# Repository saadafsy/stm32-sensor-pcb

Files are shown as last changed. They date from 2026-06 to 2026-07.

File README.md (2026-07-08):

# STM32F411 Sensor Telemetry Board — Firmware

Bare-metal C (no HAL, direct CMSIS) + FreeRTOS firmware for a custom **4-layer** STM32F411RET6
sensor telemetry board. A BME280 environmental sensor and a 128×64 **SSD1306 OLED** share one
400 kHz I²C bus, arbitrated by a FreeRTOS mutex. Sensor readings are framed with a CRC-16/CCITT
protocol and streamed at 921600 baud over a CP2102N USB-UART bridge to a Python visualizer.

<p align="center">
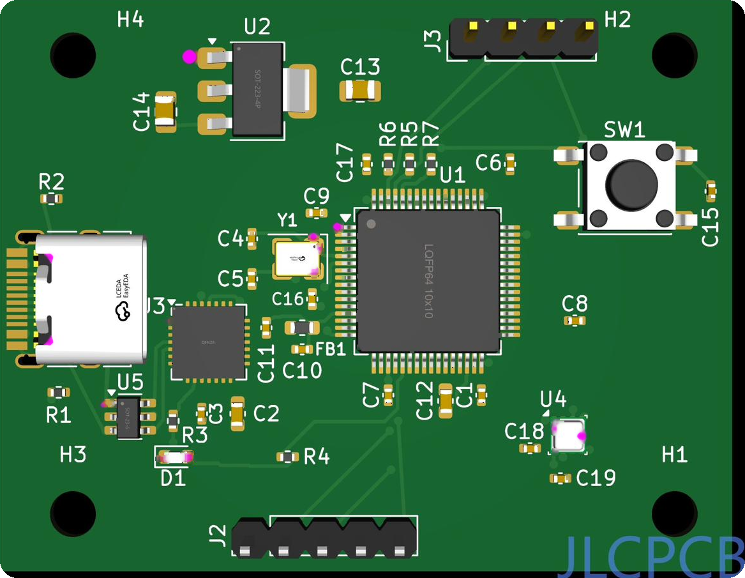
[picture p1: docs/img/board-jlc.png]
  
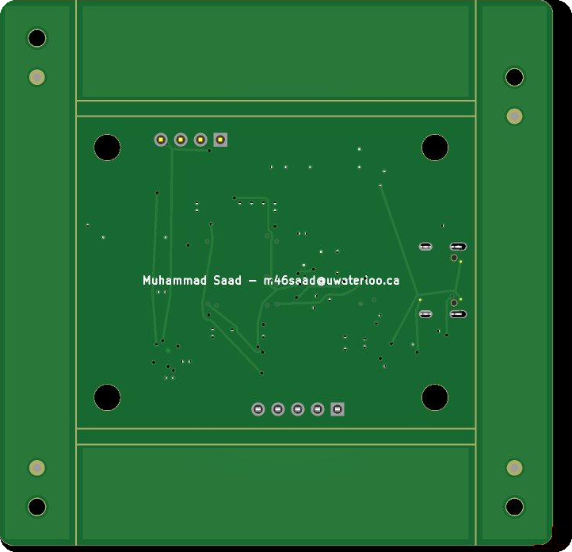
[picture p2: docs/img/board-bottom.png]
  
</p>

## Architecture — four FreeRTOS tasks
- **sensor_task** — reads + Bosch-compensates the BME280 over I²C, pushes samples to a queue
- **telemetry_task** — builds the CRC-framed binary packet and sends it under a UART mutex
- **display_task** — renders pages to the SSD1306; a **PA0/EXTI0 button** cycles pages via an ISR notification
- **heartbeat_task** — blinks the PA5 LED and kicks the IWDG watchdog

Shared I²C access is protected by an `i2c_mutex`; an `i2c_bus_recovery()` routine frees a wedged bus.

## Hardware (locked spec)
- MCU: **STM32F411RET6, LQFP-64** (LCSC C94355)
- PCB: **4-layer** — `F.Cu` signal / `In1.Cu` ground plane / `In2.Cu` +3V3 plane / `B.Cu` signal, 1.6 mm FR4
- BME280 @ I²C **0x77** (SDO→+3V3) · SSD1306 @ I²C **0x3C** · CP2102N USB-UART
- Clock: 8 MHz HSE → PLL → 100 MHz

## Layout
```
Core/Inc/   headers (clock, gpio, uart, i2c, bme280, crc, protocol, ssd1306, iwdg, FreeRTOSConfig)
Core/Src/   sources (+ main.c with the four tasks and the EXTI button ISR)
tools/      visualize.py — host-side telemetry viewer
hardware/   KiCad project (schematic, PCB, project)
docs/img/   board renders
```

## Build
Import into **STM32CubeIDE** as a bare-metal + FreeRTOS project for the STM32F411RET6
(develop on a NUCLEO-F411RE, deploy on the custom PCB). Flash over SWD/ST-Link.

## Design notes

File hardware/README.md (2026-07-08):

# Hardware

Custom 4-layer PCB designed in KiCad 9 (stackup: F.Cu / inner GND / inner +3V3 / B.Cu).

- `sensor-telemetry-board.kicad_pro` - project
- `sensor-telemetry-board.kicad_sch` - schematic
- `sensor-telemetry-board.kicad_pcb` - 4-layer layout

## Key parts

| Ref | Part | Role |
|-----|---|---|
| U1 | STM32F411CEU6 | MCU (Cortex-M4F, 100 MHz) |
| U? | BME280 | temperature / humidity / pressure over I2C |
| U? | CP2102N | USB-C to UART bridge |
| U? | AMS1117-3.3 | 3.3 V LDO |
| U? | USBLC6-2 | USB data-line ESD protection |
| Y1 | 8 MHz crystal | HSE reference for the 100 MHz PLL |

## Status

Design complete and DFM-validated (POFV across all vias); Gerbers, BOM, and CPL
can be regenerated from this project for a JLCPCB PCBA order. The board is in shipping 
and will be brought up soon (see the top-level README for status).

To export fabrication files: open the project in KiCad and run the Fabrication
Toolkit plugin, or export Gerbers / drill / BOM / CPL manually from the PCB and
schematic editors.

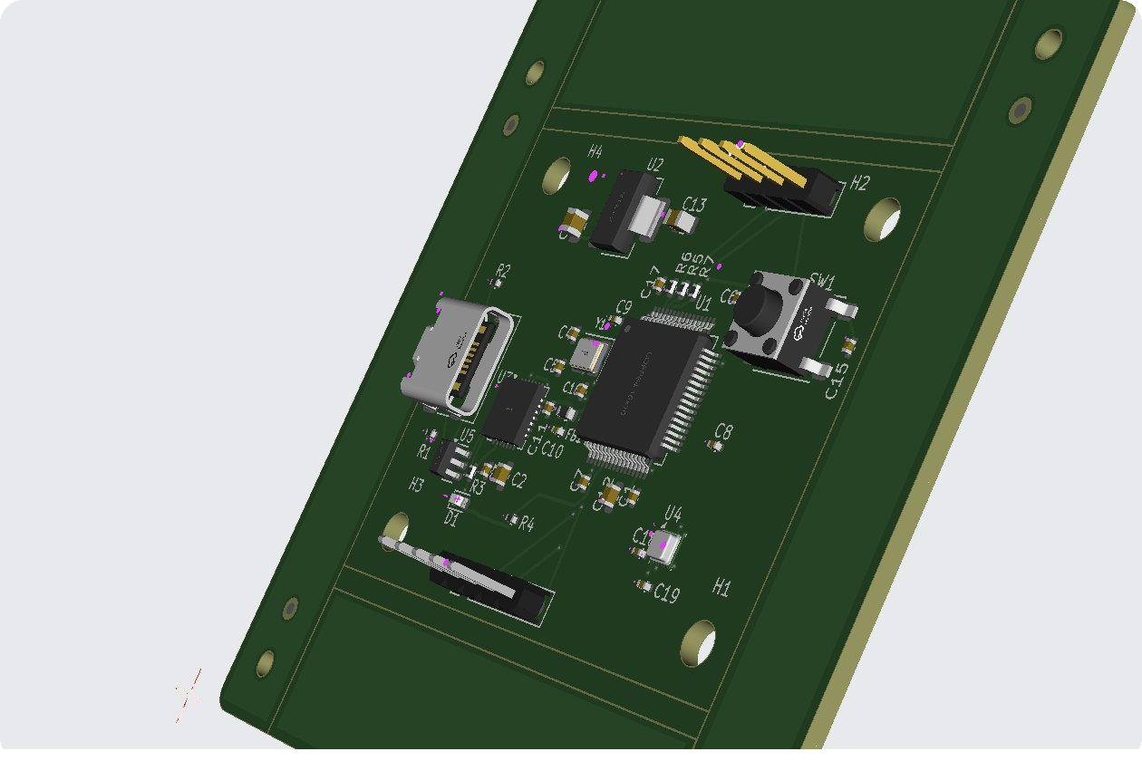
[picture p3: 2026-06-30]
docs/img/board-angled.png

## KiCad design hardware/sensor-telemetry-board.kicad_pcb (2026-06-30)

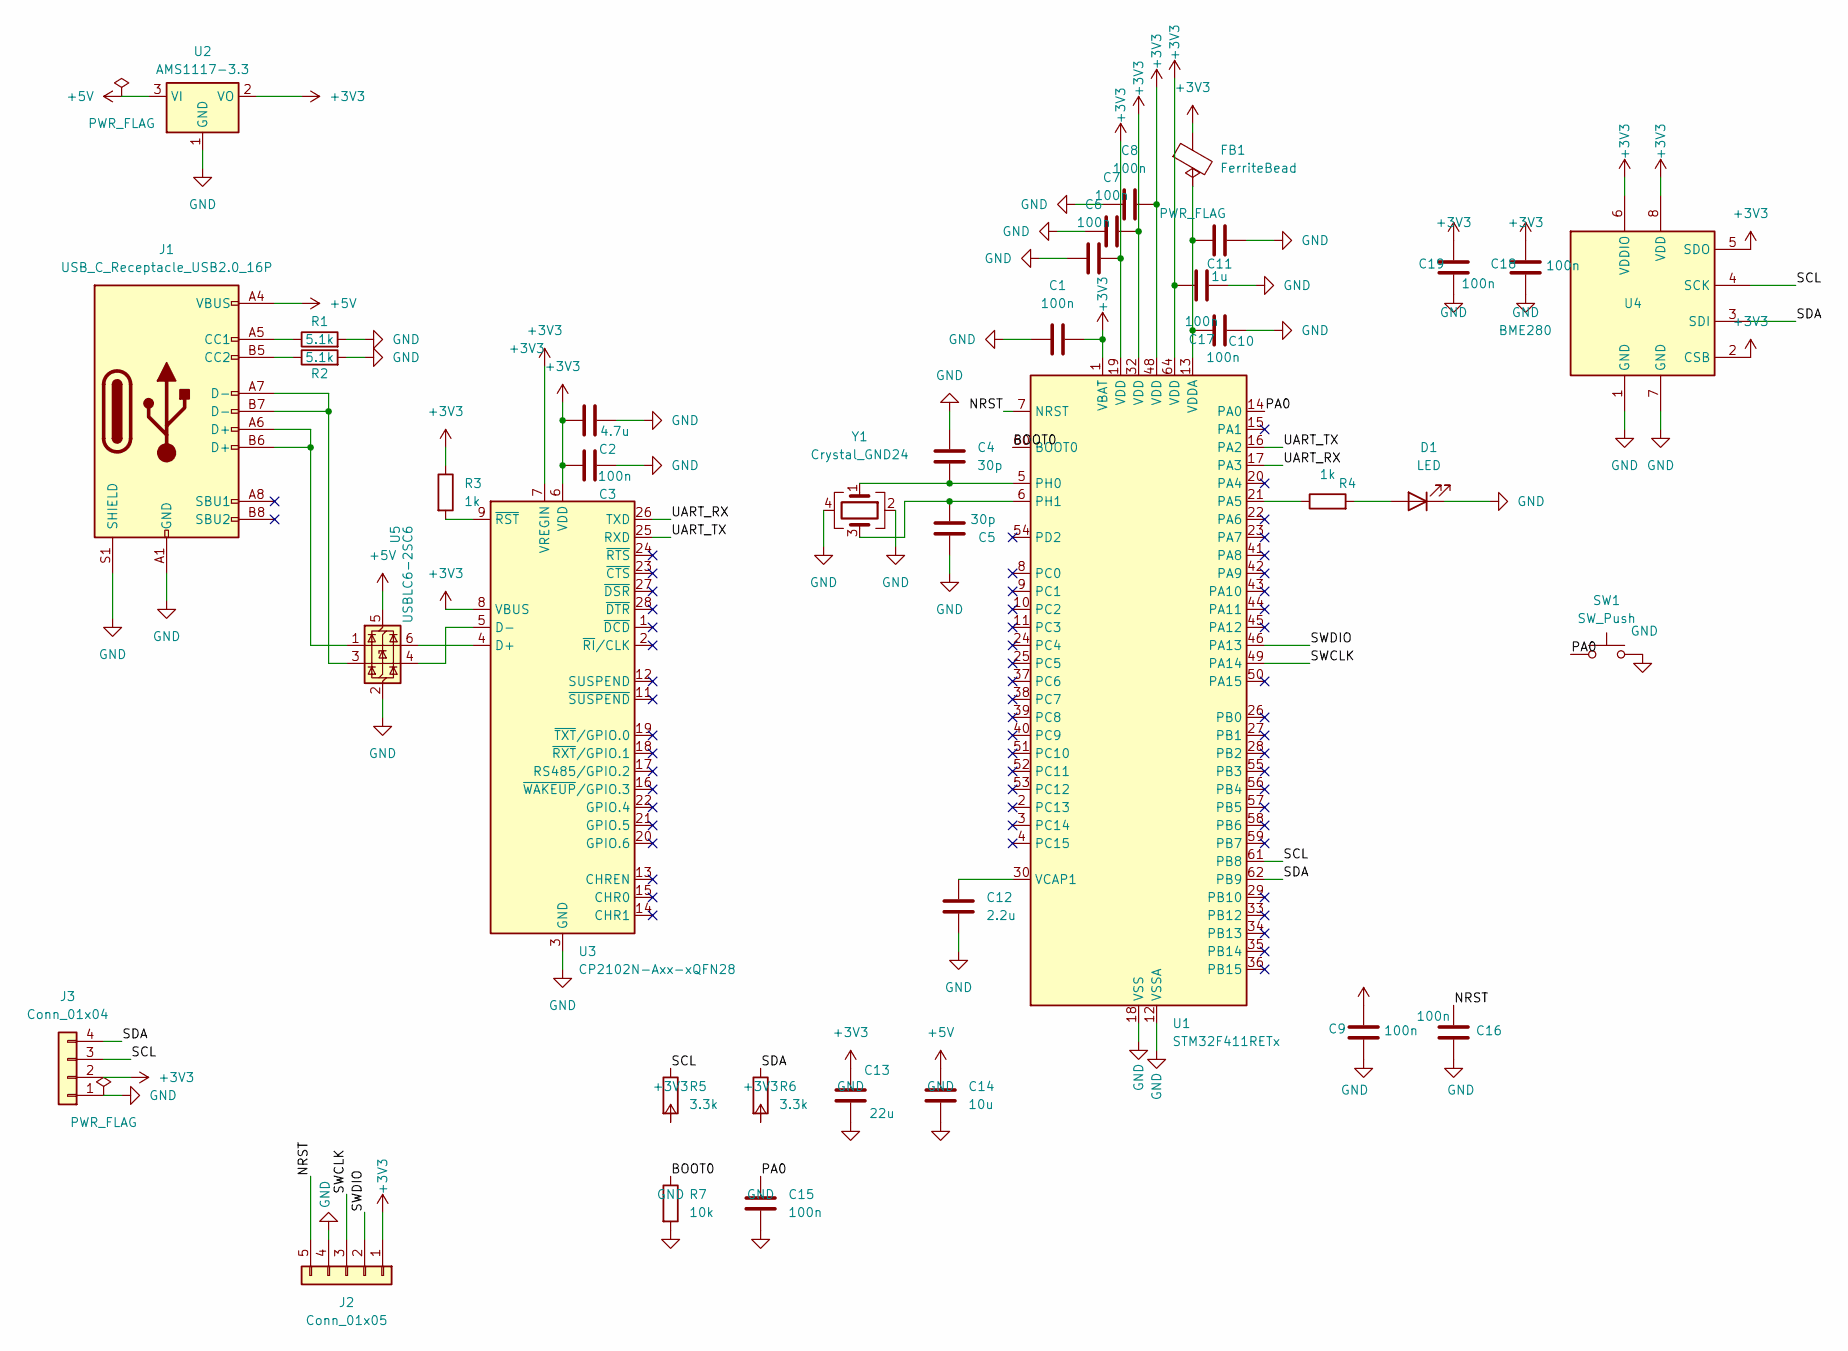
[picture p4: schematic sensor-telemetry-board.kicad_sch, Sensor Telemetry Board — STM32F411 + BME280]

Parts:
C1, C3, C6, C7, C8, C9, C10, C15, C16, C17, C18, C19: 100n; C_0402_1005Metric
C2: 4.7u; C_0603_1608Metric
C4, C5: 30p; C_0402_1005Metric
C11: 1u; C_0402_1005Metric
C12: 2.2u; C_0603_1608Metric
C13: 22u; C_0805_2012Metric
C14: 10u; C_0805_2012Metric
D1: LED; LED_0603_1608Metric
FB1: FerriteBead; L_0603_1608Metric
J1: USB_C_Receptacle_USB2.0_16P; USB_C_Receptacle_HRO_TYPE-C-31-M-12
J2: Conn_01x05; PinHeader_1x05_P2.54mm_Vertical
J3: Conn_01x04; PinHeader_1x04_P2.54mm_Vertical
R1, R2: 5.1k; R_0402_1005Metric
R3, R4: 1k; R_0402_1005Metric
R5, R6: 3.3k; R_0402_1005Metric
R7: 10k; R_0402_1005Metric
SW1: SW_Push; SW_SPST_PTS645Sx43SMTR92
U1: STM32F411RETx; LQFP-64_10x10mm_P0.5mm
U2: AMS1117-3.3; SOT-223-3_TabPin2
U3: CP2102N-Axx-xQFN28; QFN-28-1EP_5x5mm_P0.5mm_EP3.35x3.35mm
U4: BME280; Bosch_LGA-8_2.5x2.5mm_P0.65mm_ClockwisePinNumbering
U5: USBLC6-2SC6; SOT-23-6
Y1: Crystal_GND24; Crystal_SMD_3225-4Pin_3.2x2.5mm

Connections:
+3V3: C1.2, C2.2, C3.2, C6.2, C7.2, C8.2, C9.1, C13.1, C17.2, C18.1, C19.1, FB1.1, J2.1, J3.2, R3.1, R5.2, R6.2, U1.1 (VBAT), U1.19 (VDD), U1.32 (VDD), U1.48 (VDD), U1.64 (VDD), U2.2 (VO), U3.6 (VDD), U3.7 (VREGIN), U3.8 (VBUS), U4.2 (CSB), U4.5 (SDO), U4.6 (VDDIO), U4.8 (VDD)
+5V: C14.1, J1.A4 (VBUS), J1.A9 (VBUS), J1.B4 (VBUS), J1.B9 (VBUS), U2.3 (VI), U5.5 (VBUS)
/BOOT0: R7.1, U1.60 (BOOT0)
/NRST: C16.1, J2.5, U1.7 (NRST)
/PA0: C15.1, SW1.1, U1.14 (PA0)
/SCL: J3.3, R5.1, U1.61 (PB8), U4.4 (SCK)
/SDA: J3.4, R6.1, U1.62 (PB9), U4.3 (SDI)
/SWCLK: J2.3, U1.49 (PA14)
/SWDIO: J2.2, U1.46 (PA13)
/UART_RX: U1.17 (PA3), U3.26 (TXD)
/UART_TX: U1.16 (PA2), U3.25 (RXD)
GND: C1.1, C2.1, C3.1, C4.1, C5.1, C6.1, C7.1, C8.1, C9.2, C10.1, C11.1, C12.2, C13.2, C14.2, C15.2, C16.2, C17.1, C18.2, C19.2, D1.1 (K), J1.A1 (GND), J1.A12 (GND), J1.B1 (GND), J1.B12 (GND), J1.S1 (SHIELD), J2.4, J3.1, R1.2, R2.2, R7.2, SW1.2, U1.12 (VSSA), U1.18 (VSS), U1.31 (VSS), U1.47 (VSS), U1.63 (VSS), U2.1 (GND), U3.3 (GND), U3.29 (GND), U4.1 (GND), U4.7 (GND), U5.2 (GND), Y1.2, Y1.4
unnamed: D1.2 (A), R4.2
unnamed: J1.A5 (CC1), R1.1
unnamed: J1.B5 (CC2), R2.1
unnamed: J1.A6 (D+), J1.B6 (D+), U5.1 (I/O1)
unnamed: J1.A7 (D-), J1.B7 (D-), U5.3 (I/O2)
unnamed: R4.1, U1.21 (PA5)
unnamed: C4.2, U1.5 (PH0), Y1.1
unnamed: C5.2, U1.6 (PH1), Y1.3
unnamed: C12.1, U1.30 (VCAP1)
unnamed: C10.2, C11.2, FB1.2, U1.13 (VDDA)
unnamed: U3.4 (D+), U5.6 (I/O1)
unnamed: U3.5 (D-), U5.4 (I/O2)
unnamed: R3.2, U3.9 (~RST)

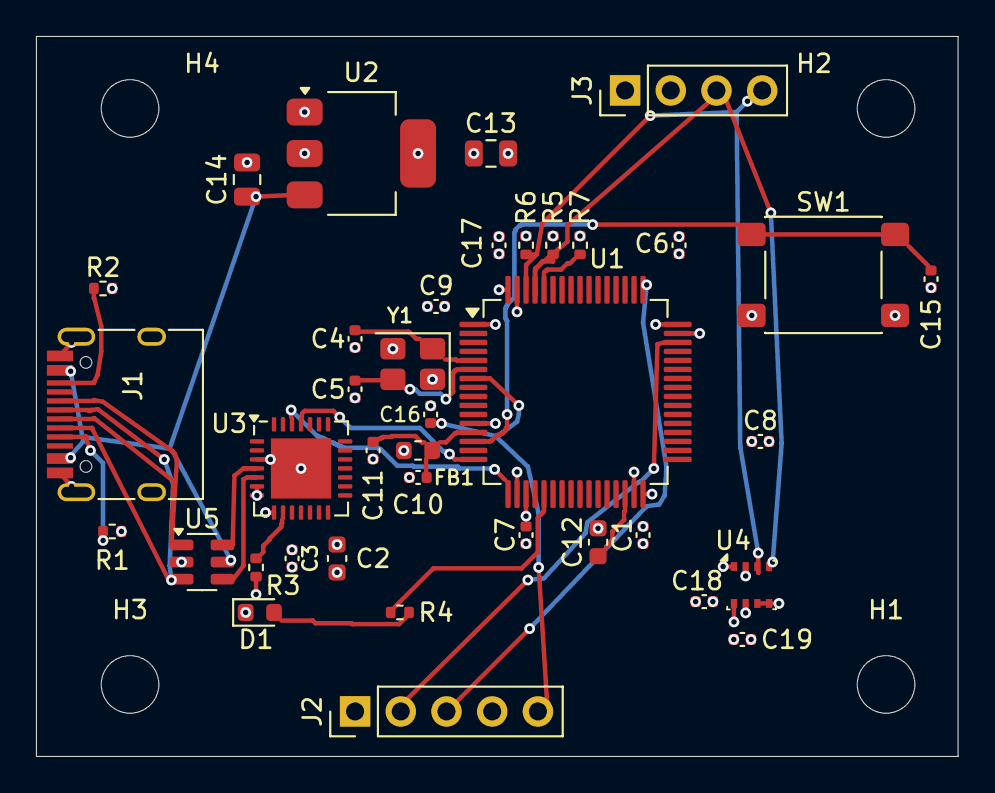
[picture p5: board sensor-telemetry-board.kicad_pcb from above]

Board: 4 copper layers, 51.2 x 40.0 mm, 42 parts (0 on the bottom side), 25 nets.

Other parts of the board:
H1, H2, H3, H4: MountingHole_3.2mm_M3

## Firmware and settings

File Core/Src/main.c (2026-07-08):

#include "stm32f4xx.h"
#include <stdio.h>
#include <stdlib.h>
#include "FreeRTOS.h"
#include "task.h"
#include "queue.h"
#include "semphr.h"
#include "clock.h"
#include "gpio.h"
#include "uart.h"
#include "i2c.h"
#include "bme280.h"
#include "protocol.h"
#include "ssd1306.h"
#include "iwdg.h"
/* The unit that flows sensor -> telemetry through the queue. */
typedef struct {
 int32_t temp_c100; /* 0.01 C */
 uint32_t press_q24_8; /* >>8 = Pa */
 uint32_t hum_q22_10; /* >>10 = %RH */
 uint32_t seq;
} sensor_sample_t;
static QueueHandle_t sample_q; /* producer/consumer FIFO */
static SemaphoreHandle_t uart_mutex; /* owns the UART resource */
static SemaphoreHandle_t i2c_mutex; /* the I2C bus is shared: sensor + display */
static sensor_sample_t g_latest; /* last good reading, shared with the display */
static volatile int g_have_sample = 0;
static TaskHandle_t display_task_handle; /* notified by the button ISR */
static volatile uint8_t g_display_page = 0; /* which OLED page is shown */
static volatile uint32_t g_frames_sent = 0; /* telemetry frames sent (status)*/
static int32_t g_tmin_c100, g_tmax_c100; /* temp min/max (under crit.) */
#define DISPLAY_PAGES 3
/* --- producer: reads the sensor (shares the I2C bus via i2c_mutex) --- */
static void sensor_task(void *arg)
{
 (void)arg;
 int rc = -1;
 for (int attempt = 0; attempt < 3; attempt++) {
 xSemaphoreTake(i2c_mutex, portMAX_DELAY);
 rc = bme280_init();
 if (rc != 0) i2c_bus_recovery(); /* a stuck bus or slow-waking sensor often clears */
 xSemaphoreGive(i2c_mutex);
 if (rc == 0) break;
 vTaskDelay(pdMS_TO_TICKS(50));
 }
 if (rc != 0) {
 /* Say what kind of failure, once, then idle so the rest of the system stays alive.
 * rc == -2: no ACK on the bus (wiring / pull-ups / address / CSB-not-tied).
 * rc == -1: a device answered but it isn't a BME280 (e.g. 0x58 = BMP280). */
 xSemaphoreTake(uart_mutex, portMAX_DELAY);
 uart_write(rc == -2 ? "[err] BME280: no I2C ACK (check wiring/pull-ups/addr/CSB)\r\n"
 : "[err] BME280: wrong chip ID (got a BMP280? expected 0x60)\r\n");

 xSemaphoreGive(uart_mutex);
 vTaskDelete(NULL);
 }
 uint32_t seq = 0;
 for (;;) {
 sensor_sample_t s;
 xSemaphoreTake(i2c_mutex, portMAX_DELAY);
 int r = bme280_read(&s.temp_c100, &s.press_q24_8, &s.hum_q22_10);
 if (r != 0) i2c_bus_recovery(); /* stuck bus: clock SDA free, SWRST, re-init */
 xSemaphoreGive(i2c_mutex);
 if (r != 0) { vTaskDelay(pdMS_TO_TICKS(250)); continue; } /* don't ship a bad sample */
 s.seq = seq++;
 taskENTER_CRITICAL(); /* hand the latest reading to the display */
 if (!g_have_sample) { g_tmin_c100 = g_tmax_c100 = s.temp_c100; }
 else { if (s.temp_c100 < g_tmin_c100) g_tmin_c100 = s.temp_c100;
 if (s.temp_c100 > g_tmax_c100) g_tmax_c100 = s.temp_c100; }
 g_latest = s; g_have_sample = 1;
 taskEXIT_CRITICAL();
 xQueueSend(sample_q, &s, 0); /* non-blocking: drop if full */
 vTaskDelay(pdMS_TO_TICKS(250)); /* yield CPU for 250 ms */
 }
}
/* --- consumer: blocks on the queue, packs a CRC frame, transmits under the mutex --- */
static void telemetry_task(void *arg)
{
 (void)arg;
 sensor_sample_t s;
 uint8_t frame[FRAME_TOTAL_LEN];
 for (;;) {
 if (xQueueReceive(sample_q, &s, portMAX_DELAY) == pdTRUE) { /* sleep until data */
 uint32_t press_pa = s.press_q24_8 >> 8; /* Q24.8 -> Pa */
 uint32_t hum_c100 = (s.hum_q22_10 * 100u) >> 10; /* Q22.10 -> 0.01 %RH */
 uint32_t n = protocol_build(frame, s.seq, s.temp_c100, press_pa, hum_c100);
 xSemaphoreTake(uart_mutex, portMAX_DELAY);
 for (uint32_t i = 0; i < n; i++) uart_putc((char)frame[i]); /* length-bounded:
 a frame byte may be 0x00, so never use
 uart_write() (it would stop at the 0x00) */
 xSemaphoreGive(uart_mutex);
 g_frames_sent++; /* for the status page */
 }
 }
}
/* ASCII debug option: during bring-up you may prefer a human-readable line you can read
 * in any terminal. Keep an #ifdef DEBUG_ASCII branch that snprintf()s
 * "T=.. H=.. P=.. seq=.." and uart_write()s it instead of the frame. Ship the frame. */
/* --- display: paints the latest reading on the OLED (shares I2C via i2c_mutex).
 * The button ISR notifies this task to flip pages; otherwise it self-refreshes. */
static void display_task(void *arg)
{
 (void)arg;
 xSemaphoreTake(i2c_mutex, portMAX_DELAY);
 ssd1306_init(); /* full driver in section 11.10 */
 xSemaphoreGive(i2c_mutex);

 for (;;) {
 sensor_sample_t s; int have; int32_t tmin, tmax;
 taskENTER_CRITICAL(); /* copy the shared snapshot + min/max quickly */
 s = g_latest; have = g_have_sample; tmin = g_tmin_c100; tmax = g_tmax_c100;
 taskEXIT_CRITICAL();
 uint32_t up = xTaskGetTickCount() / configTICK_RATE_HZ; /* seconds since boot */
 char line[20];
 ssd1306_clear(); /* draw into the RAM framebuffer (no I2C) */
 if (!have) {
 ssd1306_draw_string(0, 0, "warming up...");
 } else if (g_display_page == 0) { /* PAGE 0: live readings */
 int32_t t = s.temp_c100;
 uint32_t pp = (s.press_q24_8 >> 8) / 100u;
 uint32_t hh = s.hum_q22_10 >> 10;
 snprintf(line, sizeof line, "Temp %ld.%01ld C", (long)(t/100), (long)((t%100)/10));
 ssd1306_draw_string(0, 0, line);
 snprintf(line, sizeof line, "Hum %lu %%", (unsigned long)hh); 
ssd1306_draw_string(0, 2, line);
 snprintf(line, sizeof line, "Pres %lu hPa", (unsigned long)pp); 
ssd1306_draw_string(0, 4, line);
 snprintf(line, sizeof line, "seq %lu", (unsigned long)s.seq); 
ssd1306_draw_string(0, 6, line);
 } else if (g_display_page == 1) { /* PAGE 1: status / health */
 ssd1306_draw_string(0, 0, "-- status --");
 snprintf(line, sizeof line, "up %lu s", (unsigned long)up); 
ssd1306_draw_string(0, 2, line);
 snprintf(line, sizeof line, "frames %lu", (unsigned long)g_frames_sent); 
ssd1306_draw_string(0, 4, line);
 snprintf(line, sizeof line, "heap %u", (unsigned)xPortGetFreeHeapSize()); 
ssd1306_draw_string(0, 6, line);
 } else { /* PAGE 2: min / max temp */
 ssd1306_draw_string(0, 0, "-- min/max --");
 snprintf(line, sizeof line, "Tmin %ld.%01ld", (long)(tmin/100), (long)((tmin%100)/
10)); ssd1306_draw_string(0, 2, line);
 snprintf(line, sizeof line, "Tmax %ld.%01ld", (long)(tmax/100), (long)((tmax%100)/
10)); ssd1306_draw_string(0, 4, line);
 snprintf(line, sizeof line, "page %u/%u", (unsigned)(g_display_page+1), 
(unsigned)DISPLAY_PAGES); ssd1306_draw_string(0, 6, line);
 }
 xSemaphoreTake(i2c_mutex, portMAX_DELAY);
 ssd1306_flush(); /* push the framebuffer over I2C */
 xSemaphoreGive(i2c_mutex);
 ulTaskNotifyTake(pdTRUE, pdMS_TO_TICKS(500)); /* wake on button press, else 2 Hz refresh 
*/
 }
}
/* --- heartbeat: proves the scheduler is preempting --- */
static void heartbeat_task(void *arg)
{
 (void)arg;
 led_init();

 for (;;) {
 led_toggle();
 iwdg_refresh(); /* kick the watchdog from the lowest-priority task 
*/
 vTaskDelay(pdMS_TO_TICKS(500)); /* toggle every 500 ms => 1 Hz blink */
 }
}
/* Button ISR (PA0/EXTI0): the deferred-interrupt pattern. Do the bare minimum here
 * and hand the real work (repaint) to the display task via a task notification. */
void EXTI0_IRQHandler(void)
{
 static TickType_t last = 0;
 if (EXTI->PR & (1U << 0)) {
 EXTI->PR = (1U << 0); /* clear the pending bit (write 1) */
 TickType_t now = xTaskGetTickCountFromISR();
 if ((now - last) >= pdMS_TO_TICKS(200)) { /* software debounce: ignore < 200 ms */
 last = now;
 g_display_page = (uint8_t)((g_display_page + 1) % DISPLAY_PAGES);
 BaseType_t woken = pdFALSE;
 vTaskNotifyGiveFromISR(display_task_handle, &woken);
 portYIELD_FROM_ISR(woken); /* switch to the display task if it outranks 
us */
 }
 }
}
int main(void)
{
 clock_init(); /* 100 MHz first */
 NVIC_SetPriorityGrouping(3); /* all 4 priority bits = preemption, 0 sub-priority: FreeRTOS's 
requirement (NVIC_PRIORITYGROUP_4) */
 usart2_init();
 i2c1_init();
 button_init(); /* PA0 EXTI0 for the display-page button */
 iwdg_init(); /* start the ~1.6 s watchdog; heartbeat_task kicks it */
 uart_write("\r\n[boot] p1 sensor telemetry @100MHz\r\n");
 sample_q = xQueueCreate(8, sizeof(sensor_sample_t));
 uart_mutex = xSemaphoreCreateMutex();
 i2c_mutex = xSemaphoreCreateMutex(); /* shared I2C bus: sensor + display */
 /* priorities: sensor(2) > telemetry(1) = display(1) = heartbeat(1) > idle(0).
 * stacks in WORDS: telemetry and display both use snprintf, so give them room. */
 xTaskCreate(sensor_task, "sensor", 256, NULL, 2, NULL);
 xTaskCreate(telemetry_task, "telem", 256, NULL, 1, NULL);
 xTaskCreate(display_task, "disp", 256, NULL, 1, &display_task_handle);
 xTaskCreate(heartbeat_task, "hb", 128, NULL, 1, NULL);
 vTaskStartScheduler(); /* never returns once tasks are running */
 for (;;) { } /* only reached if the heap was too small to start */
}

void vApplicationStackOverflowHook(TaskHandle_t xTask, char *pcTaskName)
{
 (void)xTask; (void)pcTaskName;
 taskDISABLE_INTERRUPTS();
 /* Breakpoint here: pcTaskName names the culprit task. */
 for (;;) { }
}
void vApplicationMallocFailedHook(void)
{
 taskDISABLE_INTERRUPTS();
 for (;;) { } /* heap exhausted: raise configTOTAL_HEAP_SIZE */
}

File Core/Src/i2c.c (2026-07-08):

/* i2c.c — I2C1 master, fast mode 400 kHz, PCLK1 = 50 MHz. Polled (no IRQ/DMA).
 * Return codes (transfer functions): 0 = OK, -1 = timeout (stuck bus / lost
 * clock-stretch), -2 = address NACK (no device answered). A production driver never
 * spins forever on a hardware flag: one wedged slave would hang the whole task. */
#include "stm32f4xx.h"
#include "i2c.h"

#define I2C_TIMEOUT  100000U   /* per-wait loop budget; ~a few ms at 100 MHz, >> any 400 kHz byte */

/* Spin until COND; give up after I2C_TIMEOUT tries -> force STOP, return -1.
 * (Using `return` inside a macro is a deliberate, documented bare-metal idiom here.) */
#define WAIT(cond) do {                                                   \
    uint32_t _to = I2C_TIMEOUT;                                           \
    while (!(cond)) {                                                      \
        if (--_to == 0u) { I2C1->CR1 |= I2C_CR1_STOP; return -1; }         \
    }                                                                      \
} while (0)

/* Wait for the bus to be idle before a transfer. */
#define WAIT_IDLE() do {                                                  \
    uint32_t _to = I2C_TIMEOUT;                                           \
    while (I2C1->SR2 & I2C_SR2_BUSY) { if (--_to == 0u) return -1; }       \
} while (0)

/* Wait for ADDR, but bail out if the slave NACKs the address (AF set = nobody home). */
#define WAIT_ADDR() do {                                                  \
    uint32_t _to = I2C_TIMEOUT;                                           \
    while (!(I2C1->SR1 & I2C_SR1_ADDR)) {                                  \
        if (I2C1->SR1 & I2C_SR1_AF) {                                      \
            I2C1->SR1 &= ~I2C_SR1_AF;       /* clear the NACK flag */      \
            I2C1->CR1 |= I2C_CR1_STOP;      /* release the bus    */       \
            return -2;                                                     \
        }                                                                  \
        if (--_to == 0u) { I2C1->CR1 |= I2C_CR1_STOP; return -1; }         \
    }                                                                      \
} while (0)

void i2c1_init(void)
{
    /* --- clocks --- */
    RCC->AHB1ENR |= RCC_AHB1ENR_GPIOBEN;          /* port B clock */
    RCC->APB1ENR |= RCC_APB1ENR_I2C1EN;           /* I2C1 clock   */

    /* --- PB8 = SCL, PB9 = SDA: alternate function AF4, OPEN-DRAIN, with pull-ups ---
     * Open-drain is mandatory for I2C: a pin may only pull low or release.
     * We enable the internal pull-ups too so the breadboard works even if you
     * forget externals; on the PCB you add 4.7k externals and these are backup. */
    GPIOB->MODER   &= ~((3U << (8 * 2)) | (3U << (9 * 2)));
    GPIOB->MODER   |=  ((2U << (8 * 2)) | (2U << (9 * 2)));   /* 10 = alternate fn */
    GPIOB->OTYPER  |=  ((1U << 8) | (1U << 9));               /* 1  = open-drain   */
    GPIOB->OSPEEDR |=  ((3U << (8 * 2)) | (3U << (9 * 2)));   /* high speed        */
    GPIOB->PUPDR   &= ~((3U << (8 * 2)) | (3U << (9 * 2)));
    GPIOB->PUPDR   |=  ((1U << (8 * 2)) | (1U << (9 * 2)));   /* 01 = pull-up      */
    GPIOB->AFR[1]  &= ~((0xFU << ((8 - 8) * 4)) | (0xFU << ((9 - 8) * 4)));
    GPIOB->AFR[1]  |=  ((4U   << ((8 - 8) * 4)) | (4U   << ((9 - 8) * 4))); /* AF4 */
    /* AFR[1] is the "high" alternate-function register, covering pins 8..15.
     * Pin 8 -> nibble 0, pin 9 -> nibble 1, hence the (pin-8)*4 shift. */

    /* --- peripheral config: software-reset first, then timing --- */
    I2C1->CR1 |=  I2C_CR1_SWRST;                   /* hold peripheral in reset  */
    I2C1->CR1 &= ~I2C_CR1_SWRST;                   /* release: clean known state */

    I2C1->CR2 = (I2C1->CR2 & ~I2C_CR2_FREQ) | 50U; /* tell I2C its input clock is 50 MHz */

    /* CCR for fast mode, duty 16/9:  Tscl = 25 * CCR * Tpclk1.
     * For 400 kHz: Tscl = 2.5 us, Tpclk1 = 20 ns  ->  CCR = 2500/(25*20) = 5. */
    I2C1->CCR = I2C_CCR_FS | I2C_CCR_DUTY | 5U;

    /* TRISE = (max SCL rise / Tpclk1) + 1 = (300 ns / 20 ns) + 1 = 16  (fast mode). */
    I2C1->TRISE = 16U;

    I2C1->CR1 |= I2C_CR1_PE;                        /* enable the peripheral */
}

/* Write one byte VAL into register REG of the device at 7-bit address ADDR7. */
int i2c_write_reg(uint8_t addr7, uint8_t reg, uint8_t val)
{
    WAIT_IDLE();                                    /* bus must be idle */

    I2C1->CR1 |= I2C_CR1_START;                     /* generate START   */
    WAIT(I2C1->SR1 & I2C_SR1_SB);                   /* EV5: START sent  */

    I2C1->DR = (uint8_t)((addr7 << 1) | 0);         /* 7-bit addr + WRITE bit (0) */
    WAIT_ADDR();                                    /* EV6: addr ACKed (NACK -> return -2) */
    (void)I2C1->SR1; (void)I2C1->SR2;               /* clear ADDR: read SR1 THEN SR2 */

    WAIT(I2C1->SR1 & I2C_SR1_TXE);                  /* data register ready */
    I2C1->DR = reg;                                 /* send the register pointer */

    WAIT(I2C1->SR1 & I2C_SR1_TXE);
    I2C1->DR = val;                                 /* send the value */

    WAIT(I2C1->SR1 & I2C_SR1_BTF);                  /* both bytes fully shifted out */
    I2C1->CR1 |= I2C_CR1_STOP;                       /* release the bus */
    return 0;
}
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
